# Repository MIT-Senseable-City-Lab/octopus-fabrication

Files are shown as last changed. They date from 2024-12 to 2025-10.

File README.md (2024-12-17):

# Octopus Fabrication Repository

The Octopus Fabrication Repository contains all the necessary files to build the mechanical and electronic components of the Octopus system. This guide provides resources for assembling the hardware and electronics schematics, including 3D printing files. Whether you're fabricating the device for research, prototyping, or field use, this repository simplifies the process.

Learn more about the **octopus documentation** [here](https://mit-senseable-city-lab.github.io/octopus-documentation/docs/home).

### **Mechanical Parts**  
All 3D design files are provided as described in the [Mechanics Documentation](https://mit-senseable-city-lab.github.io/octopus-documentation/docs/build/mechanics).  
You can choose your preferred version of the Octopus system based on your project needs.

- **[octopus top layer (head)](https://github.com/MIT-Senseable-City-Lab/octopus-fabrication/blob/main/octopus_top_nano.stl)** for Arduino nano and **[octopus top layer (head)](https://github.com/MIT-Senseable-City-Lab/octopus-fabrication/blob/main/octopus_top_nikla.stl)** for Arduino nicla
- **[octopus middle layer](https://github.com/MIT-Senseable-City-Lab/octopus-fabrication/blob/main/octopus_bottom.stl)**
- **[octopus bottom layer (legs)](https://github.com/MIT-Senseable-City-Lab/octopus-fabrication/blob/main/octopus_bottom.stl)**

### **Electronics Parts**  

All hardware-related files for the electronics components are located in the [hardware](/hardware) directory. This includes:  

- **[Gerber Files](https://github.com/MIT-Senseable-City-Lab/octopus-fabrication/blob/main/hardware/octopus_gerberfiles.zip)**: For PCB and PCBA fabrication.  
- **[Bill of Materials (BOM)](https://github.com/MIT-Senseable-City-Lab/octopus-fabrication/blob/main/hardware/octopus_BOM.xlsx)**: A complete list of all the electronic components needed for the PCBs.  
- **[Schematics](https://github.com/MIT-Senseable-City-Lab/octopus-fabrication/blob/main/hardware/octopus_schematic.pdf)**: Detailed electronic schematics in PDF format.

To learn more:  
- Refer to the **[Electronics Documentation](https://mit-senseable-city-lab.github.io/octopus-documentation/docs/build/electronics)** for details on required tools.  
- Follow the [Assembly Guide](https://mit-senseable-city-lab.github.io/octopus-documentation/docs/build/assembly) for step-by-step instructions on assembling the electronics components.

All materials are released under [MIT license](LICENSE).

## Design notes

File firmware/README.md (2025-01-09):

# Octopus Firmware Library

The Octopus Firmware Library provides easy-to-use functions and examples to help you get started with the Arduino Nano 33 BLE Sense and Nicla Vision boards. Whether you're a beginner or an experienced maker, this library offers a simple starting point and advanced features to expand your projects.

## Quick Installation

### Step 1: Install the Library via Arduino Library Manager
1. Open the Arduino IDE.
2. Go to `Tools` > `Manage Libraries..`.
3. Search for **Octopus Firmware** and click `Install`.

### Step 2: Install Required Dependencies
When prompted to install the required dependencies, select "Install all." (Note: If you have previously installed the necessary dependencies, this prompt may not appear.)
Install these additional libraries from the Arduino Library Manager:
- **Adafruit_DotStar**
- **sensirion-sps**
- **Arduino_HS300x**
- **ArduinoBLE**
- **SD**
- **SparkFun_u-blox_GNSS_Arduino_Library**

### Firmware Usage Guide
### Example: Reading Temperature and Humidity

Here's a simple code snippet to demonstrate reading both temperature and humidity using the Octopus Firmware Library:

```cpp
#include "octopus.h"

void setup() {
    Serial.begin(9600);
    Octopus::initializeSensors();  // Initialize the sensors
}

void loop() {
    float temperature = Octopus::readTemperature();  // Read temperature
    float humidity = Octopus::readHumidity();        // Read humidity
    
    Serial.print("Temperature: ");
    Serial.print(temperature);
    Serial.println(" °C");

    Serial.print("Humidity: ");
    Serial.print(humidity);
    Serial.println(" %");

    delay(1000); // Read temperature and humidity every second
}
```
## Main Functions and Usage

### 1. Initializing Sensors and GPS
- **Initialize Sensors**: Use `Octopus::initializeSensors()` to initialize all connected sensors.
- **Initialize GPS**: Use `Octopus::initializeGPS()` to start the GPS functionality and prepare it for data retrieval.

### 2. Reading Temperature and Humidity
- **Read Temperature**: Use `Octopus::readTemperature()` to get the current temperature in degrees Celsius.
- **Read Humidity**: Use `Octopus::readHumidity()` to obtain the current humidity percentage.

### 3. Managing Device State with Button Press
- **Button Control**: Use a button to toggle the device state between on and off.
  - A **short press** turns the device on.
  - A **long press** (2 seconds) turns the device off.

### 4. Reading and Logging GPS Data
- **Retrieve GPS Time**: Use `Octopus::getGPSTime()` to get the current GPS time as a string.
- **Read GPS Coordinates**: Use `Octopus::readGPSData()` to read GPS coordinates (latitude, longitude) and altitude.

### 5. Reading Particulate Matter Data (SPS30)
- **Read Particulate Matter**: If the SPS30 sensor is available, use `Octopus::readSPS30Data()` to get particulate matter readings (PM1.0, PM2.5, PM4.0, PM10.0).

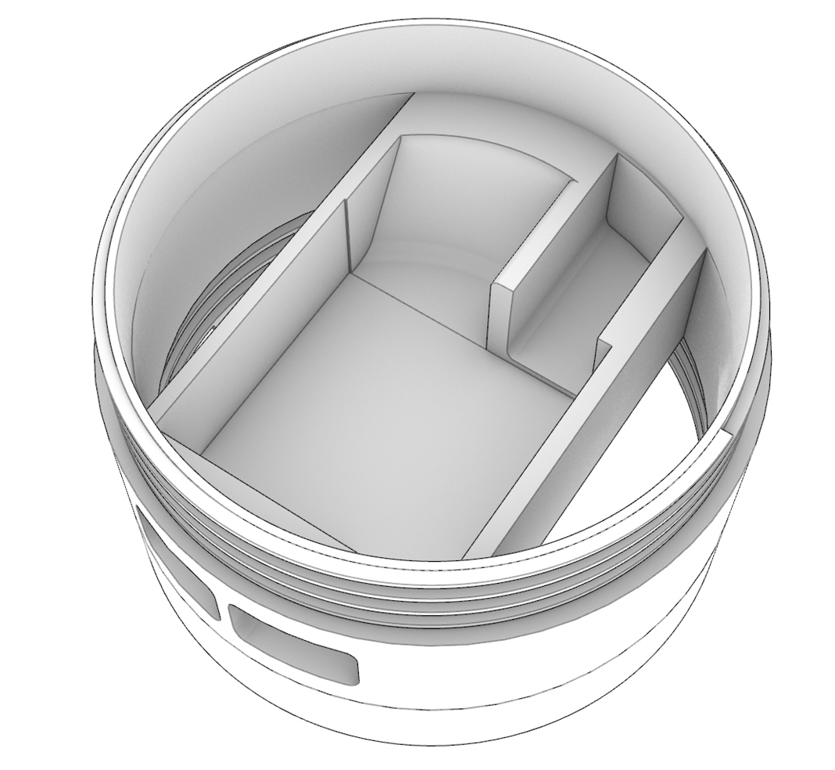
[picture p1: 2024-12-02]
imgs/otopus_middle-layer_perspective.png

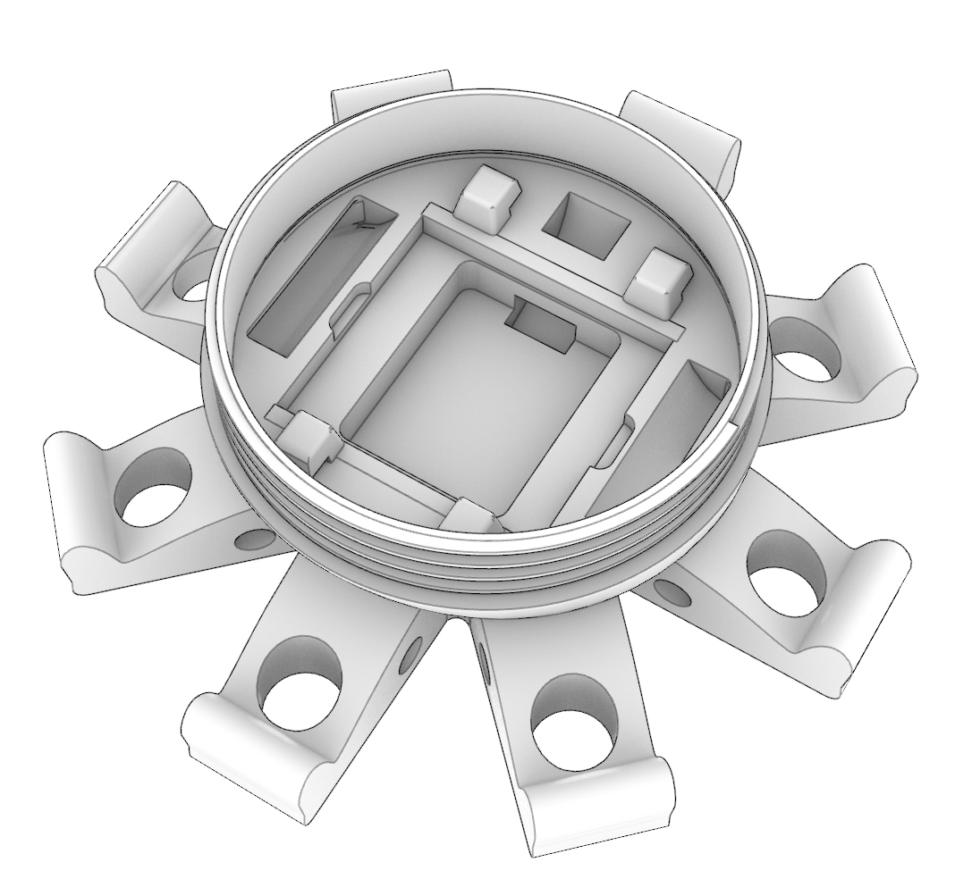
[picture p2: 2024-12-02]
imgs/otopus_bottom-layer_perspective.png

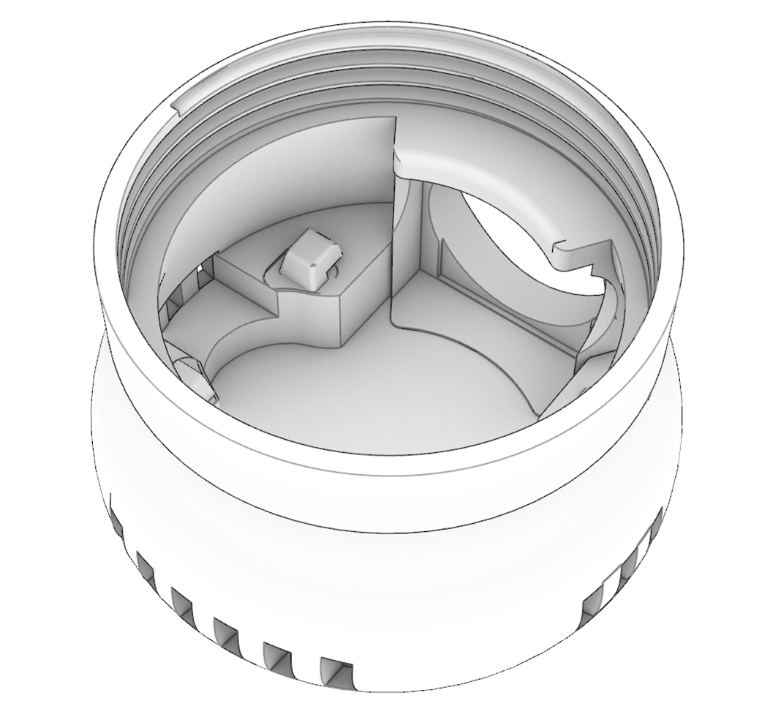
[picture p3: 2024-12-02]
imgs/otopus_top-layer_perspective.png

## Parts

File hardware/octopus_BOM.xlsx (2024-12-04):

CUSTOMER |  | MIT
PROJECT |  | 2024-XXXX (OCTOPUS)
REVISION |  | 4
SCHEMATIC |  | 2024XXXX_OCTOPUS_V4
DATA |  | 2024-12-04
DRAFTED |  | M. Gregis
APPROVED |  | -
Item | Quantity | Reference | Part | MPN | MPN2 | MPN3 | MPN4 | Description | Temperature | Distributor | Pkg Type | Package | Database
1 | 1 | CS1 | CS V4 4L 35um |  |  |  |  | C.S. OCTOPUS V4 (7x7)mm HAL 4L Cu=35um | TG130 | WE-ONLINE | Nome Approved
2 | 5 | C1,C6,C8,C9,C11 | 100n/50V |  |  |  |  | CHIP CAP.CER. 100nF 50V 10% X7R 0805 |  | FAE | SMD | CS-C-0805 | 10516
3 | 2 | C2,C3 | 4.7u/50V-X5R | C2012X5R1H475K125AB |  |  |  | CHIP CAP.CER. 4.7uF 50V 10% X5R 0805 | -55..+85 |  | SMD | CS-C-0805
4 | 2 | C4,C5 | 10u/25V-X5R |  |  |  |  | CHIP CAP.CER. 10uF 25V 10% X5R 0805 | -55..+125 |  | SMD | CS-C-0805
5 | 1 | C7 | 0.33F/5.5V | CB5R5334HF-ZJP |  |  |  | COND.EL.RAD. 0.33F 5.5V -20%+80% P=10 D=11.5x7.5 CB5R5334HF-ZJP CDA | -25°..85° |  | THT | CT-1150-1000
6 | 1 | C10 | 22u/10V-X5R |  |  |  |  | CHIP CAP.CER. 22uF 10V 20% X5R 0805 |  | FAE | SMD | CS-C-0805 | 35227
7 | 5 | DS1,DS2,DS3,DS4,DS5 | PMEG1030EJ | PMEG1030EJ,115 |  |  |  | DIODO SCHOTTKY 3A 10V PMEG1030EJ NXP SOD323 SMT | -55°..125° |  | SMD | SOD323
8 | 1 | J1 | B2B-PH-K-S | B2B-PH-K-S |  |  |  | CONN. PH 2P M P=2 B2B-PH-K-S JST THT |  |  | THT | J-2-0200-MDT-B2B
9 | 1 | J4 | SSM-102-L-SV | SSM-102-L-SV |  |  |  | STRIP 2P F/D P=2.54 SSM-102-L-SV SAMTEC SMT | -55..105 |  | SMT | J-2-0254-FDS-SSM
10 | 1 | J5 | SSM-108-L-SV | SSM-108-L-SV |  |  |  | STRIP 8P F/D P=2.54 SSM-108-L-SV SAMTEC SMT | -40..105° |  | SMD | J-8-0254-FDS-SSM
11 | 1 | J6 | SSM-109-L-SV | SSM-109-L-SV |  |  |  | STRIP 9P F/D P=2.54 SSM-109-L-SV SAMTEC SMT | -55°..105° |  | SMT | J-9-0254-FDS-SSM
12 | 1 | J7 | BM04B-SRSS-TBT | BM04B-SRSS-TBT(LF)(SN) |  |  |  | CONN. SH 4P M/D P=1 BM04B-SRSS-TBT(LF)(SN) JST SMT | -25°..+85° | D-455-2874-1-ND | SMD | J-4-0100-MDS-SH
13 | 1 | J8 | B5B-ZR-SM4-TF | B5B-ZR-SM4-TF |  |  |  | CONN. ZH 5P M/D P=1.5 ZH JST B5B-ZR-SM4-TF | -25°..+85° | D-455-1684-1-ND | SMD | J-5-0150-MDS-B5B-ZR-SM4
14 | 1 | J9 | MSD-4-A | MSD-4-A |  |  |  | CONN. MICROSD 9P F/90° PUSH-PUSH MSD-4-A MOLEX SMT | -40°..+85° | FAE | SMD | J-9-0110-FOS-MSD-4-A
15 | 1 | LD1 | 150141YS73100 | 150141YS73100 |  |  |  | DIODO LED GIALLO 150141YS73100 WURTH SMT | -40°..+85° |  | SMD | LD-3228
16 | 2 | LD2,LD3 | T3A33BRG-H9C0002X1U1930 | T3A33BRG-H9C0002X1U1930 |  |  |  | DIODO LED RGB T3A33BRG-H9C0002X1U1930 HARVATEK SMT | -40..85° |  | SMD | LD-T3A33
17 | 1 | L1 | LQM2HPN4R7MG0L | LQM2HPN4R7MG0L |  |  |  | INDUTTANZA 4.7uH 1.1A 20% 1008 LQM2HPN4R7MG0L MURATA SMT | -40°..+125° |  | SMD | LS-1008
18 | 1 | PB1 | FSM4JSMAATR |  |  |  |  | PULSANTE 24V 0.05A D=6x6 SPST FSM4JSMAATR TE SMT | -35°..+85° | FAE | SMD | PB-OT-FSM4J
19 | 1 | R1 | 523R | CRCW0805523RFKEA |  |  |  | CHIP RES. 523R 0805 1/8W 1% 100PPM/°C |  |  | SMD | RS-0805
20 | 2 | R2,R5 | 120k | RC0805FR-07120KL |  |  |  | CHIP RES. 120K 0805 1/8W 1% 100PPM/°C |  |  | SMD | RS-0805
21 | 1 | R3 | 430k |  |  |  |  | CHIP RES. 430K 0805 1/8W 1% |  | FAE | SMD | RS-0805 | 17583
22 | 1 | R4 | 2.8k | RC0805FR-072K8L |  |  |  | CHIP RES. 2K8 0805 1/8W 1% 100PPM/°C |  |  | SMD | RS-0805
23 | 1 | R6 | 180k | RC0805FR-07180KL |  |  |  | CHIP RES. 180K 0805 1/8W 1% 100PPM/°C |  |  | SMD | RS-0805
24 | 2 | R7,R8 | 4.7k |  |  |  |  | CHIP RES. 4K7 0805 1/8W 1% |  | FAE | SMD | RS-0805 | 15005
25 | 7 | R9,R10,R11,R12,R13,R15,R16 | 33k |  |  |  |  | CHIP RES. 33K 0805 1/8W 1% 100PPM/°C |  |  | SMD | RS-0805
26 | 1 | R14 | 470R |  |  |  |  | CHIP RES. 470R 0805 1/8W 1% |  | FAE | SMD | RS-0805 | 43376
27 | 1 | R17 | 10k |  |  |  |  | CHIP RES. 10K 0805 1/8W 1% |  | FAE | SMD | RS-0805 | 11062
28 | 1 | R18 | 1.5k |  |  |  |  | CHIP RES. 1K5 0805 1/8W 1% |  | FAE | SMD | RS-0805 | 11781
29 | 1 | TVS1 | DT2042-04SO-7 | DT2042-04SO-7 |  |  |  | DIODO TVS UNIDIR. DT2042-04SO-7 DIODES SOT23-6 SMT |  |  | SMD | SOT23-6-DBV
30 | 1 | U1 | MCP73833T-AMI/UN | MCP73833T-AMI/UN |  |  |  | INTEGRATO BATTERY MANAGEMENT MCP73833T-AMI/UN MICROCHIP MSOP10 SMT | -40°..+85° |  | SMD | MSOP10
31 | 1 | U2 | MCP1642B-50I/MS | MCP1642B-50I/MS |  |  |  | INTEGRATO BOOST MCP1642B-50I/MS MICROCHIP DFN8 SMT | -40°..+85° |  | SMD | MSOP8
32 | 1 | U3 | RX-8025SA:AA | RX-8025SA:AA | RX-8025SA:AA0 | RX-8025SA:AA3 | RX-8025SA:AA PURE SN | INTEGRATO CLOCK RX-8025SA:AA EPSON TIMING SOP14 SMT | -40°..+85° |  | SMD | SOP14
NOT MOUNTED
33 | 6 | FID1,FID2,FID3,FID4,FID5,FID6 | TPS |  |  |  |  | FIDUCIAL |  | FAE | SMD | FIDUCIAL
34 | 2 | J2,J3 | NU | SSM-115-L-SV |  |  |  | STRIP 15P F/D P=2.54 SSM-115-L-SV SAMTEC SMT | -55°..105° |  | SMT | J-15-0254-FDS-SSM
35 | 1 | J10 | NU | BOB-00544 |  |  |  | CONN. MICROSD 7P F/90° PUSH-PUSH BOB-00544 SPARKFUN THT | -40°..+85° |  | SMD | J-7-0254-BOB-00544
36 | 2 | PAD3,PAD4 | TPS |  |  |  |  | PAD THT |  | FAE | THT | PAD-THT-R-0202-0102
37 | 75 | PAD9,PAD10,PAD11,PAD12,PAD13,PAD14,PAD15,PAD16,PAD17,PAD18,PAD19,PAD20,PAD25,PAD26,PAD27,PAD28,PAD29,PAD30,PAD31,PAD32,PAD33,PAD34,PAD35,PAD36,PAD41,PAD42,PAD43,PAD44,PAD45,PAD46,PAD47,PAD48,PAD49,PAD50,PAD51,PAD52,PAD57,PAD58,PAD59,PAD60,PAD61,PAD62,PAD63,PAD64,PAD65,PAD66,PAD67,PAD68,PAD73,PAD74,PAD75,PAD76,PAD77,PAD78,PAD79,PAD80,PAD81,PAD82,PAD83,PAD84,PAD89,PAD90,PAD91,PAD92,PAD93,PAD94,PAD95,PAD96,PAD97,PAD98,PAD99,PAD100,PAD184,PAD185,PAD187 | TPS |  |  |  |  | PAD SMD |  | FAE | SMD | PAD-0150X0150
37 | 3 | PAD182,PAD183,PAD186 | TPS |  |  |  |  | PAD SMD |  |  | SMD | PAD-0100X0350

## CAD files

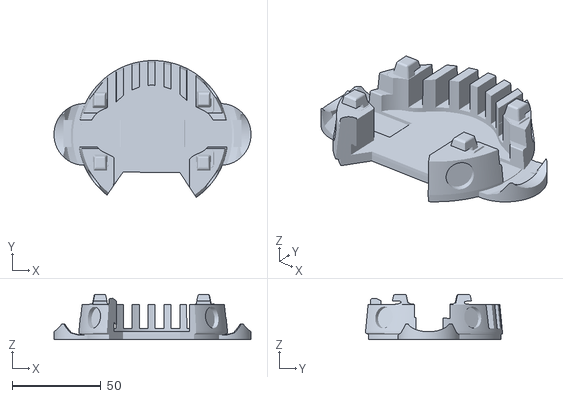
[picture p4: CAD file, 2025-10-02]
octopus_cap_nano.stl
111.1 x 77.2 x 25.6

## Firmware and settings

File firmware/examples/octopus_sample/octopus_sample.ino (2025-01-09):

#include "Octopus_Firmware.h"

unsigned long previousMillis = 0;
const long interval = 5000; // Interval in milliseconds
unsigned long blinkInterval = 100; // Blinking interval in milliseconds
unsigned long lastBlinkMillis = 0;
bool isBlinkOn = false;

// Button state variables
const int buttonPin = 7;  // Pin connected to the button
bool deviceOn = false; // Device state
bool longPressHandled = false; // To ensure long press is handled once
unsigned long buttonPressTime = 0;
const unsigned long longPressDuration = 2000; // Duration to consider as long press (2000ms)

const int RECORDS_PER_FILE = 10;
const int vbatPin = A0;         
const int chargeStatePin = 7;  

const float coldThreshold = 20.0; 
const float hotThreshold = 25.0;  

// Sensor availability flags
bool sps30Available = false;
bool gpsAvailable = false;

void setup() {
    Serial.begin(9600);
    Serial.println("Starting Octopus Device...");

    // Initialize sensors
    Serial.println("Initializing sensors...");
    if (!Octopus::initializeSensors()) {
        Serial.println("Failed to initialize sensors. Continuing...");
    } else {
        Serial.println("Sensors initialized.");
    }
  // Attempt to initialize GPS
    Serial.println("Initializing GPS...");
    gpsAvailable = Octopus::initializeGPS();
    if (!gpsAvailable) {
        Serial.println("GPS not detected.");
    } else {
        Serial.println("GPS initialized.");
    }

    // Attempt to initialize SPS30
    Serial.println("Initializing SPS30...");
    sps30Available = Octopus::initializeSPS30();
    if (!sps30Available) {
        Serial.println("SPS30 not detected.");
    } else {
        Serial.println("SPS30 initialized.");
    }

    // Continue startup even if sensors failed
    Serial.println("Starting data collection...");
    if (!Octopus::start()) {
        Serial.println("Failed to start data collection.");
    } else {
        Serial.println("Data collection started.");
    }
 // Initialize SD card
    Serial.println("Initializing SD card...");
    initSD(RECORDS_PER_FILE);
    Serial.println("SD card initialized.");

    initBatteryMonitoring();

    pinMode(buttonPin, INPUT_PULLUP);
    Serial.println("Setup complete.");
}

void loop() {
    unsigned long currentMillis = millis();

    int buttonState = digitalRead(buttonPin);
    if (buttonState == LOW) {
        if (buttonPressTime == 0) {
            buttonPressTime = millis();
        }

        if ((millis() - buttonPressTime) >= longPressDuration) {
            if (!longPressHandled) {
                deviceOn = false;
                Serial.println("Device turned off");
                setDotStarColor(0, 0, 0);
                if (sps30Available) {
                    Octopus::stopSPS30();
                }
                delay(100);
                longPressHandled = true;
            }
        }
    } else {
        if (buttonPressTime != 0) {
            if (!longPressHandled) {
                deviceOn = true;
                Serial.println("Device turned on");
                initSD(RECORDS_PER_FILE);
                initBatteryMonitoring();
                if (sps30Available) {
                    Octopus::initializeSPS30();
                }
            }
            buttonPressTime = 0;
            longPressHandled = false;
            delay(50);
        }
    }

    if (!deviceOn) {
        delay(100);
        return;
    }

    if (currentMillis - previousMillis >= interval) {
        previousMillis = currentMillis; 

        // Get GPS time if available
        String gpsTime = "N/A";
        if (gpsAvailable) {
            gpsTime = Octopus::getGPSTime();
        }

        // Read GPS data if available
        float latitude = 0, longitude = 0, altitude = 0;
        if (gpsAvailable) {
            if (!Octopus::readGPSData(latitude, longitude, altitude)) {
                Serial.println("Failed to read GPS data");
            }
        }

        // Read other sensor data
        float temperature = Octopus::readTemperature();
        float humidity = Octopus::readHumidity();

        // Read SPS30 data if available
        float pm1_0 = 0, pm2_5 = 0, pm4_0 = 0, pm10_0 = 0;
        if (sps30Available) {
            if (!Octopus::readSPS30Data(pm1_0, pm2_5, pm4_0, pm10_0)) {
                Serial.println("Failed to read SPS30 data");
            }
        }

        // Log the data (Include placeholders or skip the SPS30 values if not available)
        String data = gpsTime + "," + String(latitude, 7) + "," + String(longitude, 7) + "," + temperature + "," + humidity;
        if (sps30Available) {
            data += "," + String(pm1_0) + "," + String(pm2_5) + "," + String(pm4_0) + "," + String(pm10_0);
        } else {
            data += ",N/A,N/A,N/A,N/A";  // Placeholder if SPS30 data is unavailable
        }
        logToSD(data);

        // Print the data to the Serial monitor
        Serial.print("GPS Time: ");
        Serial.println(gpsTime);
        Serial.print("Latitude: ");
        Serial.println(latitude, 7);
        Serial.print("Longitude: ");
        Serial.println(longitude, 7);
      
        // Battery monitoring and RGB LED control
        int vbatRaw = analogRead(vbatPin);
        float vbatVoltage = vbatRaw * (3.294 / 1023.0) * 1.279;
        bool chargeState = digitalRead(chargeStatePin);
        bool batteryConnected = vbatVoltage > 2.5;
        float batteryPercentage = batteryConnected ? calculateBatteryPercentage(vbatVoltage) : 0.0;

        if (temperature < coldThreshold) {
            setDotStarColor(0, 0, 255); 
        } else {
            setDotStarColor(128, 0, 128); 
        }

        if (vbatVoltage < 2.5 || !batteryConnected) {
            if (currentMillis - lastBlinkMillis >= blinkInterval) {
                lastBlinkMillis = currentMillis;
                isBlinkOn = !isBlinkOn;
                if (isBlinkOn) {
                    setDotStarColor(255, 0, 0); 
                } else {
                    setDotStarColor(0, 0, 0);
                }
            }
        }

        Serial.print("VBAT Voltage: ");
        Serial.print(vbatVoltage, 2);
        Serial.print(" V, Charge State: ");
        Serial.print(chargeState ? "Charging" : "Not Charging");
        Serial.print(", Battery Percentage: ");
        Serial.print(batteryPercentage, 1);
        Serial.println(" %");

        Serial.println();
    }

    delay(100);
}

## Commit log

2024-11-19 Create README.md
    Print settings guidelines, assembly process descriptions and short presentation of files and purposes
2024-12-04 Create samples
2024-12-04 Create pcb
2024-12-04 octopus electronics
    [octopus_BOM.xlsx]
2025-01-27 Rename octopus_top_nicla.stl
    [octopus_top_nicla.stl]
2025-01-27 Rename octopus_top_nicla_fan.stl
    [octopus_top_nicla_fan.stl]
